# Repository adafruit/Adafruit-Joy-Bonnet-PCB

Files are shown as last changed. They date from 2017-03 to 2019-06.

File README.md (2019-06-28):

## Adafruit Joy Bonnet PCB

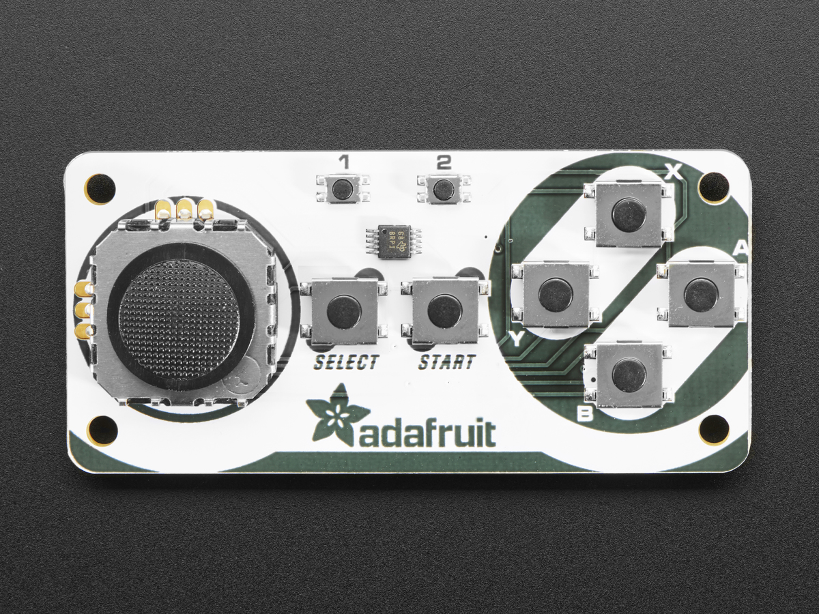
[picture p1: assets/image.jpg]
<a href="http://www.adafruit.com/products/3464"><br/>
Click here to purchase one from the Adafruit shop</a>

PCB files for the Adafruit Joy Bonnet for Raspberry Pi. Format is EagleCAD schematic and board layout
* http://www.adafruit.com/product/3464

### Description

Pocket-sized fun is the name of this game, with the Joy Bonnet – our most fun Bonnet ever (no we didn't even think that was possible, either!). This Bonnet fits perfectly on top of your Raspberry Pi Zero (any kind) and gives you adorable hand-held arcade controls. Once you install our script onto your Pi, the controls will act like a keyboard, for easy use with any emulator or media player.

Personally, we found this Bonnet to work best with RetroPie/EmulationStation. On a Pi Zero we could emulate NES and MAME game (our favorites!) but other emulators that don't require more than 1GHz speeds will work OK too, e.g. a N64 emulator won't work, it needs way more power!

Best of all, this Bonnet is fully assembled - no soldering at all is required. You may need to solder headers onto your Pi Zero (or use press-fit headers) but once that's done you're ready to rock. In theory you could also use this with a Pi A+ or B+/2/3 but it wouldn't be very hand-held.

### License

Adafruit invests time and resources providing this open source design, please support Adafruit and open-source hardware by purchasing products from [Adafruit](https://www.adafruit.com)!

Designed by Limor Fried/Ladyada for Adafruit Industries.

Creative Commons Attribution/Share-Alike, all text above must be included in any redistribution. See license.txt for additional details.

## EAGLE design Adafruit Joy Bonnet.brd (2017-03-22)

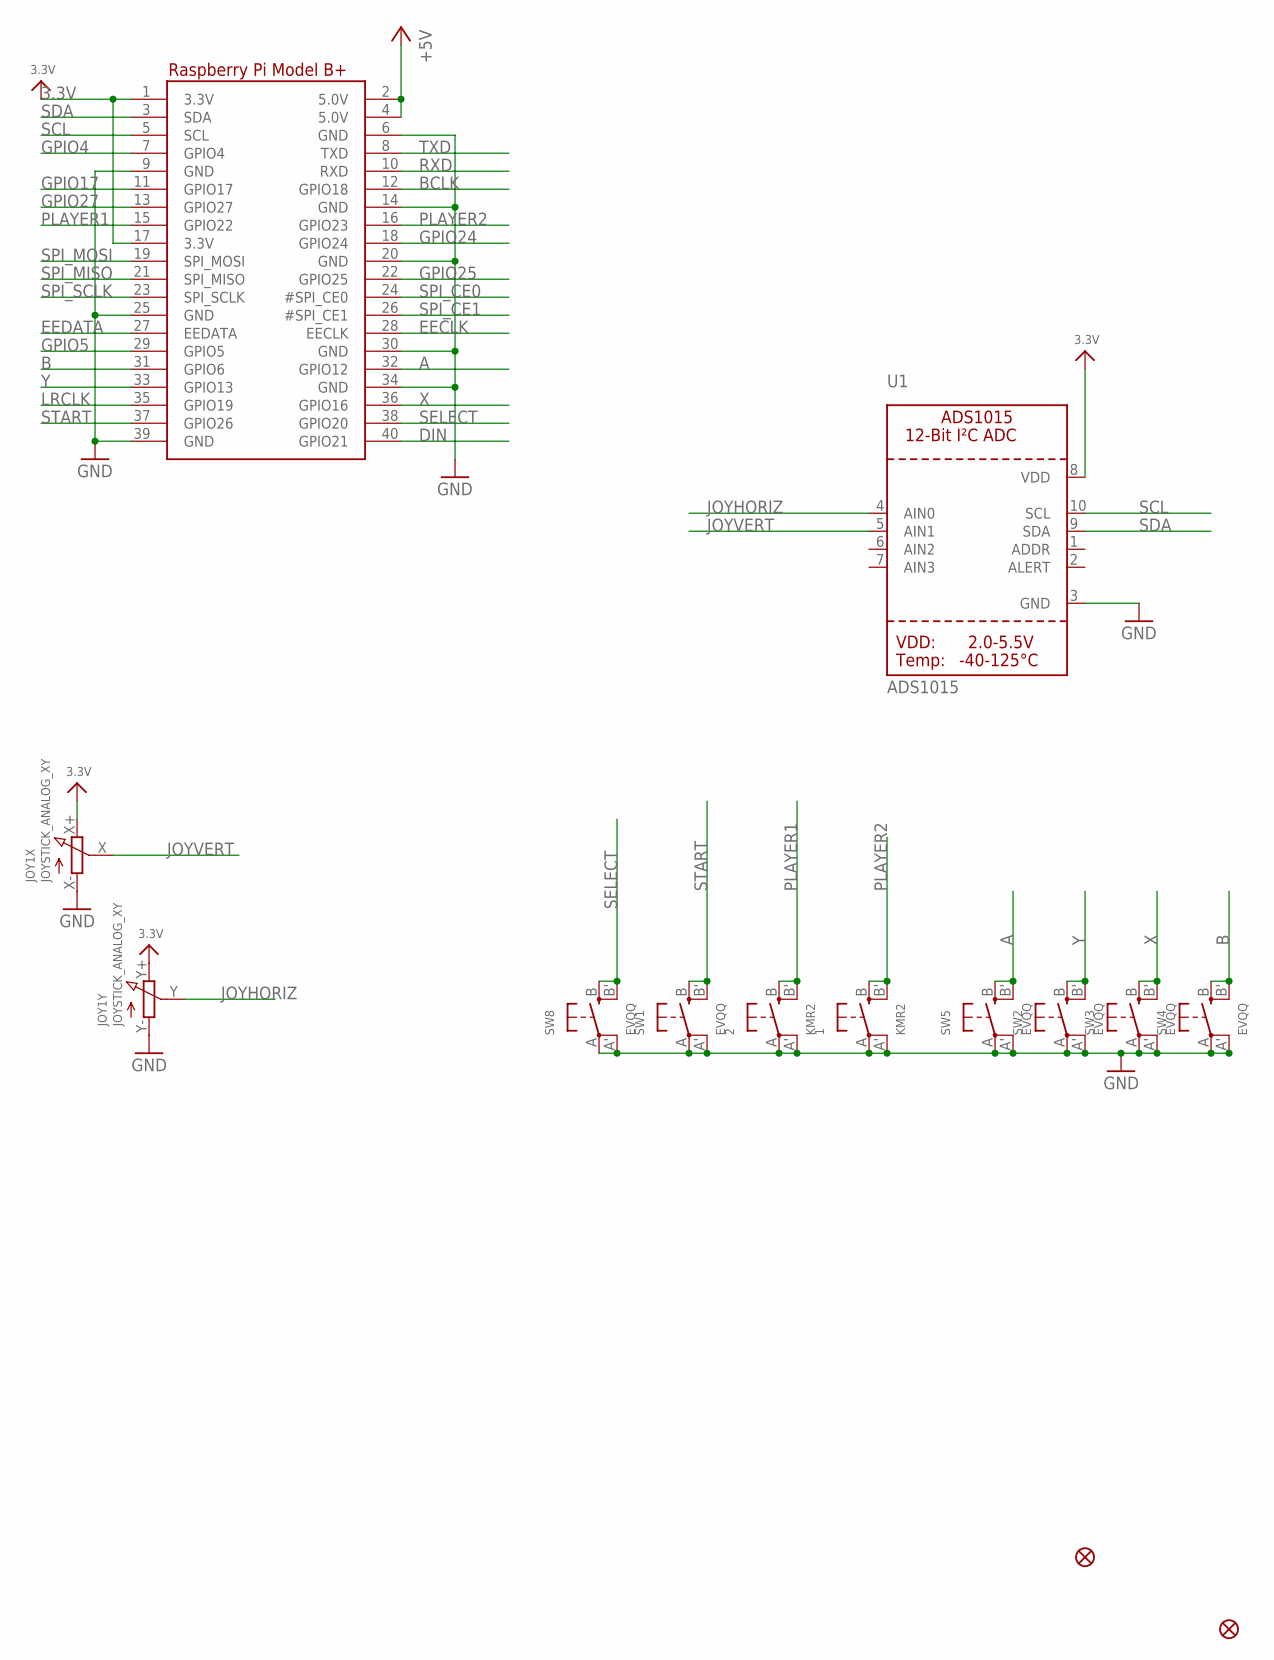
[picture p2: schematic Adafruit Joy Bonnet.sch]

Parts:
1, 2: KMR2; BTN_KMR2_4.6X2.8
FID2, FID3: FIDUCIAL_1MM
JOY1: JOYSTICK_ANALOG_XY; JOYSTICK_ANALOG_MINITHM
RPI1: RASPBERRYPI_BPLUS_BONNETSMT; PI_BONNET_SMT
SW1, SW2, SW3, SW4, SW5, SW8: EVQQ; EVQ-Q2_SMALLER
U1: ADS1015; MSOP10

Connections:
3.3V: JOY1.X+ (E), JOY1.Y+ (E), RPI1.1 (3.3V), RPI1.17 (3.3V), U1.8 (VDD)
+5V: RPI1.2 (5.0V), RPI1.4 (5.0V)
A: RPI1.32 (GPIO12), SW5.B (S), SW5.B' (S1)
B: RPI1.31 (GPIO6), SW4.B (S), SW4.B' (S1)
BCLK: RPI1.12 (GPIO18)
DIN: RPI1.40 (GPIO21)
EECLK: RPI1.28 (EECLK)
EEDATA: RPI1.27 (EEDATA)
GND: 1.A, 1.A' (P1), 2.A, 2.A' (P1), JOY1.X- (A), JOY1.Y- (A), RPI1.6 (GND), RPI1.9 (GND), RPI1.14 (GND), RPI1.20 (GND), RPI1.25 (GND), RPI1.30 (GND), RPI1.34 (GND), RPI1.39 (GND), SW1.A, SW1.A' (P1), SW2.A, SW2.A' (P1), SW3.A, SW3.A' (P1), SW4.A, SW4.A' (P1), SW5.A, SW5.A' (P1), SW8.A, SW8.A' (P1), U1.3 (GND)
GPIO4: RPI1.7 (GPIO4)
GPIO5: RPI1.29 (GPIO5)
GPIO17: RPI1.11 (GPIO17)
GPIO24: RPI1.18 (GPIO24)
GPIO25: RPI1.22 (GPIO25)
GPIO27: RPI1.13 (GPIO27)
JOYHORIZ: JOY1.Y (S), U1.4 (AIN0)
JOYVERT: JOY1.X (S), U1.5 (AIN1)
LRCLK: RPI1.35 (GPIO19)
PLAYER1: 2.B (S), 2.B' (S1), RPI1.15 (GPIO22)
PLAYER2: 1.B (S), 1.B' (S1), RPI1.16 (GPIO23)
RXD: RPI1.10 (RXD)
SCL: RPI1.5 (SCL), U1.10 (SCL)
SDA: RPI1.3 (SDA), U1.9 (SDA)
SELECT: RPI1.38 (GPIO20), SW8.B (S), SW8.B' (S1)
SPI_CE0: RPI1.24 (#SPI_CE0)
SPI_CE1: RPI1.26 (#SPI_CE1)
SPI_MISO: RPI1.21 (SPI_MISO)
SPI_MOSI: RPI1.19 (SPI_MOSI)
SPI_SCLK: RPI1.23 (SPI_SCLK)
START: RPI1.37 (GPIO26), SW1.B (S), SW1.B' (S1)
TXD: RPI1.8 (TXD)
X: RPI1.36 (GPIO16), SW3.B (S), SW3.B' (S1)
Y: RPI1.33 (GPIO13), SW2.B (S), SW2.B' (S1)

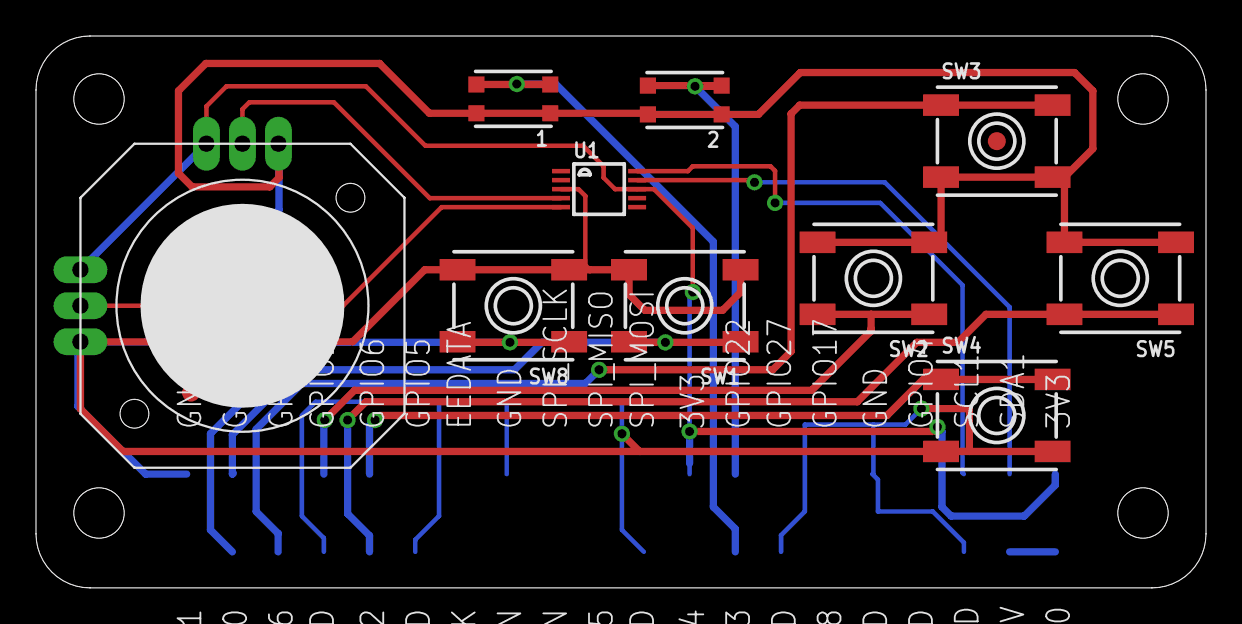
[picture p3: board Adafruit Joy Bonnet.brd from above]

Board: 2 copper layers, 65.0 x 30.7 mm, 14 parts (1 on the bottom side), 15 nets.

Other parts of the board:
U$7: PCBFEAT-REV-040

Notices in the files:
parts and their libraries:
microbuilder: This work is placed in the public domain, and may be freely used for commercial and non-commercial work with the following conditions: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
